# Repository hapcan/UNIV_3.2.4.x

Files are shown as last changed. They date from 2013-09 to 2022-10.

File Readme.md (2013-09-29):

UNIV 3.2.4.x
============

RELAY MODULE - 6 bistable 16A relays for DIN rail

Device webpage: http://hapcan.com/devices/universal/univ_3/univ_3-2-4-x/

Hardware created in Eagle PCB Software http://www.cadsoftusa.com/

Firmware created in Microchip MPLAB http://www.microchip.com/mplabide/ in assembly language

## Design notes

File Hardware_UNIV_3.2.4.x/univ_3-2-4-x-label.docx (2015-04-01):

K1 | K2 | K3 | K4 | K5 | K6

BISTABLE RELAY

6 CHANNEL

IN = 16A (IINRUSH = 30A)

UN = 250V AC
TYPE | UNIV 3.2.4.x
S/N | 00000569h
BUS BUS | | | hapcan.com

K1 | K2 | K3 | K4 | K5 | K6

PRZEKAŹNIK BISTABILNY

6 KANAŁOWY

IN = 16A (IROZRUCHOWY = 30A)

UN = 250V AC
TYP | UNIV 3.2.4.x
S/N | 00000569h
BUS BUS | | | hapcan.com

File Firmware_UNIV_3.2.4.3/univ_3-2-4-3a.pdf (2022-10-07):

## BISTABLE RELAY FIRMWARE

# UNIV 3.2.4.3

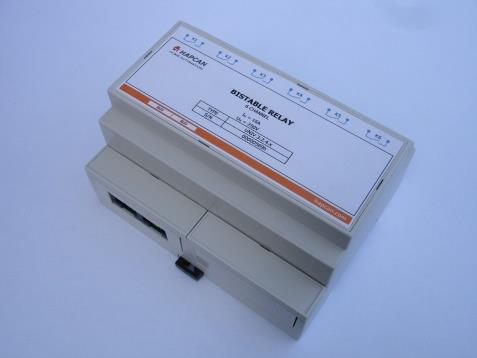
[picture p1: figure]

© 2022 hapcan.com | univ_3-2-4-3a.pdf - page 1 / 7

### 1. Features

- Firmware for 6 bistable relay module
- 3 control instructions (on, off, toggle)
- 3 blocking instructions
- 6 timers (1 for each relay) for instruction execution delay 1s-24h
- Allows defining up to 128 CAN messages which can indirectly control the module
- Settable relay power up state
- Settable relay coil polarity
- Uptime counter
- Health check monitor
- Transmit (42 messages) and receive (42 messages) FIFO buffers

### 2. Compatibility

- Firmware compatible with previous one UNIV 3.2.4.1
- Added CHANNEL NAME REQUEST frame (0x117).
- Firmware can be uploaded into processor with bootloader version 3.1 or compatible.

### 3. Firmware version

UNIV | 3 | . | 2 | . | 4 | . | 3
firmware version
application version (bistable relay 16A) application type (relay)
processor version
universal processor

### 4. Communication Frames (messages)

### 4.1. Relay message

The module sends message to the bus, when the status of relays changes.

Table 1. RELAY frame (0x302)
Frame type | Flags | Module | Group | D0 | D1 | D2 | D3 | D4 | D5 | D6 | D7
0x302 | 3 | 2 | 1 | 0 | Node Nr | Group Nr | 0xFF | 0xFF | CHANNEL | STATUS | 0xFF | INSTR1 | INSTR2 | TIMER
0x302 | – universal module frame, relay
3 | - | - not used flag, read as “0”
2 | - | - not used flag, read as “0”
1 | - | - not used flag, read as “0”
0 | RE | - response flag, flag is equal “1” if node was requested. If flag is equal „0” it means that status of output has just changed.
Node Nr | - message sender node number
Group Nr | - message sender group number
CHANNEL | - output channel
STATUS | - actual status of outputs 0x00 – relay off, 0xFF – relay on
INSTR1 | - instruction that is waiting for execution, or 0xFF if none instruction
INSTR2 | - second byte of instruction that is waiting for execution, or 0xFF
TIMER | - delay value of waiting instruction, or 0x00 if none waiting

### 4.2. Status request

Status of module can be checked by sending from computer STATUS REQUEST frame (0x109) (Table 2).

Table 2. STATUS REQUEST frame (0x109).
Frame type | Flags | Module | Group | D0 | D1 | D2 | D3 | D4 | D5 | D6 | D7
0x109 | 0x0 | COMP ID1 | COMP ID2 | 0xXX | 0xXX | Node Nr | Group Nr | 0xXX | 0xXX | 0xXX | 0xXX
0x1090 | – STATUS REQUEST frame
COMP ID1 | - computer identifier (must be unique on the network)
COMP ID2 | - computer identifier (must be unique on the network)
Node Nr | - node number of requested module
Group Nr | - group number of requested module
0xXX | - inessential data

As response the module will send RELAY frames. The meaning of bytes is the same as in Table 1.

Table 3. Response to STATUS REQUEST
Frame type | Flags | Module | Group | D0 | D1 | D2 | D3 | D4 | D5 | D6 | D7
0x302 | 0x1 | Node Nr | Group Nr | 0xFF | 0xFF | 0x01 | STATUS | 0xFF | INSTR1 | INSTR2 | TIMER1
Frame type | Flags | Module | Group | D0 | D1 | D2 | D3 | D4 | D5 | D6 | D7
0x302 | 0x1 | Node Nr | Group Nr | 0xFF | 0xFF | 0x02 | STATUS | 0xFF | INSTR1 | INSTR2 | TIMER2
Frame type | Flags | Module | Group | D0 | D1 | D2 | D3 | D4 | D5 | D6 | D7
0x302 | 0x1 | Node Nr | Group Nr | 0xFF | 0xFF | 0x03 | STATUS | 0xFF | INSTR1 | INSTR2 | TIMER3
Frame type | Flags | Module | Group | D0 | D1 | D2 | D3 | D4 | D5 | D6 | D7
0x302 | 0x1 | Node Nr | Group Nr | 0xFF | 0xFF | 0x04 | STATUS | 0xFF | INSTR1 | INSTR2 | TIMER4
Frame type | Flags | Module | Group | D0 | D1 | D2 | D3 | D4 | D5 | D6 | D7
0x302 | 0x1 | Node Nr | Group Nr | 0xFF | 0xFF | 0x05 | STATUS | 0xFF | INSTR1 | INSTR2 | TIMER5
Frame type | Flags | Module | Group | D0 | D1 | D2 | D3 | D4 | D5 | D6 | D7
0x302 | 0x1 | Node Nr | Group Nr | 0xFF | 0xFF | 0x06 | STATUS | 0xFF | INSTR1 | INSTR2 | TIMER6

### 4.3. Uptime request

Table 4. UPTIME REQUEST (0x113).
Frame type | Flags | Module | Group | D0 | D1 | D2 | D3 | D4 | D5 | D6 | D7
0x113 | 0x0 | COMP ID1 | COMP ID2 | 0xXX | 0xXX | Node Nr | Group Nr | 0xXX | 0xXX | 0xXX | 0xXX
0x1130 | – UPTIME REQUEST frame
COMP ID1 | - computer identifier (must be unique on the network)
COMP ID2 | - computer identifier (must be unique on the network)
Node Nr | - node number of requested module
Group Nr | - group number of requested module
0xXX | - inessential data

Table 5. Response to UPTIME REQUEST (0x113).
Frame type | Flags | Module | Group | D0 | D1 | D2 | D3 | D4 | D5 | D6 | D7
0x113 | 0x1 | Node Nr | Group Nr | 0xFF | 0xFF | 0xFF | 0xFF | UPTIME3 | UPTIME2 | UPTIME1 | UPTIME0
0x1131 | – Response to UPTIME REQUEST frame
Node Nr | - node number on the network
Group Nr | - group number of the node on the network
UPTIME | - (UPTIME3*256³+UPTIME2*256²+UPTIME1*256¹+UPTIME3*256⁰
) in seconds

### 4.4. Health check request

Table 6. HEALTH CHECK - STATUS REQUEST (0x115).
Frame type | Flags | Module | Group | D0 | D1 | D2 | D3 | D4 | D5 | D6 | D7
0x115 | 0x0 | COMP ID1 | COMP ID2 | 0x01 | 0xXX | Node Nr | Group Nr | 0xXX | 0xXX | 0xXX | 0xXX
0x1150 | – HEALTH CHECK REQUEST frame
COMP ID1 | - computer identifier (must be unique on the network)
COMP ID2 | - computer identifier (must be unique on the network)
0x01 | - status request
Node Nr | - node number of requested module
Group Nr | - group number of requested module
0xXX | - inessential data

As response the module will send two frames (Table 7).

Table 7. Response to HEALTH CHECK - STATUS REQUEST (0x115).
Frame type | Flags | Module | Group | D0 | D1 | D2 | D3 | D4 | D5 | D6 | D7
0x115 | 0x1 | Node Nr | Group Nr | 0x01 | RXCNT | TXCNT | RXCNTMX | TXCNTMX | CANINTCNT | RXERRCNT | TXERRCNT
0x1151 | – Response to HEALTH CHECK REQUEST frame
Node Nr | - node number on the network
Group Nr | - group number of the node on the network
0x01 | - frame 1 (current values)
RXCNT | - current level of receive FIFO buffer
TXCNT | - current level of transmit FIFO buffer
RXCNTMX | - maximum level of receive FIFO buffer since power up
TXCNTMX | - maximum level of transmit FIFO buffer since power up
CANINTCNT | - number of CAN interface restarts since power up
RXERRCNT | - current receive errors register
TXERRCNT | - current transmit errors register
Frame type | Flags | Module | Group | D0 | D1 | D2 | D3 | D4 | D5 | D6 | D7
0x115 | 0x1 | Node Nr | Group Nr | 0x02 | 0xFF | 0xFF | RXCNTMXE | TXCNTMXE | CANINTCNTE | RXERRCNTE | TXERRCNTE
0x1151 | – Response to HEALTH CHECK REQUEST frame
Node Nr | - node number on the network
Group Nr | - group number of the node on the network
0x02 | - frame 2 (maximum values saved in eeprom memory)
RXCNTMXE | - maximum ever level of receive FIFO buffer
TXCNTMXE | - maximum ever level of transmit FIFO buffer
CANINTCNTE | - maximum ever number of CAN interface restarts
RXERRCNTE | - maximum ever receive errors
TXERRCNTE | - maximum ever transmit errors

To clear maximum values saved in eeprom memory the frame shown in Table 8 must be sent. There is no response to this message.

Table 8. HEALTH CHECK - CLEAR REQUEST (0x115).
Frame type | Flags | Module | Group | D0 | D1 | D2 | D3 | D4 | D5 | D6 | D7
0x115 | 0x0 | COMP ID1 | COMP ID2 | 0x02 | 0xXX | Node Nr | Group Nr | 0xXX | 0xXX | 0xXX | 0xXX
0x1150 | – HEALTH CHECK REQUEST frame
COMP ID1 | - computer identifier (must be unique on the network)
COMP ID2 | - computer identifier (must be unique on the network)
0x02 | - clear request
Node Nr | - node number of requested module
Group Nr | - group number of requested module
0xXX | - inessential data

### 4.4. Channel name request

The module sends 5 frames for each channel containing name of channel (relay).

Table 1. CHANNEL NAME REQUEST (0x117).
Frame type | Flags | Module | Group | D0 | D1 | D2 | D3 | D4 | D5 | D6 | D7
0x117 | 0x0 | KOMP ID1 | KOMP ID2 | CHANNEL | 0xXX | Node Nr | Group Nr | 0xXX | 0xXX | 0xXX | 0xXX
0x1170 | – CHANNEL NAME REQUEST frame
COMP ID1 | - computer identifier (must be unique on the network)
COMP ID2 | - computer identifier (must be unique on the network)
CHANNEL | - requested channel number, 0x00-all channels
Node Nr | - node number of requested module
Group Nr | - group number of requested module
0xXX | - inessential data

Table 2. Response to CHANNEL NAME REQUEST (0x117).
Frame type | Flags | Module | Group | D0 | D1 | D2 | D3 | D4 | D5 | D6 | D7
0x117 | 0x1 | Node Nr | Group Nr | FRAMENR | Char1 | Char2 | Char3 | Char4 | Char5 | Char6 | Char7
0x117 | 0x1 | Node Nr | Group Nr | FRAMENR | Char8 | Char9 | Char10 | Char11 | Char12 | Char13 | Char14
0x117 | 0x1 | Node Nr | Group Nr | FRAMENR | Char15 | Char16 | Char17 | Char18 | Char19 | Char20 | Char21
0x117 | 0x1 | Node Nr | Group Nr | FRAMENR | Char22 | Char23 | Char24 | Char25 | Char26 | Char27 | Char28
0x117 | 0x1 | Node Nr | Group Nr | FRAMENR | Char29 | Char30 | Char31 | Char32 | 0x00 | 0x00 | 0x00
0x1171 | – Response to CHANNEL NAME REQUEST frame
Node Nr | - node number on the network
Group Nr | - group number of the node on the network
FRAMENR | - bits <7:3>-channel number, bits <2:1>-frame number (1-5)
| | | | CharX | - single char

### 5. Module control

The module can be controlled directly from PC, or indirectly by other modules. In both situation all instructions in the table below can be used. Blocking instructions can’t be used in direct control.

### 5.1. Control instruction

The Table 9 shows instructions, which can be executed by the module.

Table 9. Module control instructions

Instruction | Instruction Codding | Note | Control
INSTR1 | INSTR2 | INSTR3 | INSTR4 | INSTR5 | INSTR6 | INSTR7 | INSTR8
TURN OFF RELAY | 0x00 | CHANNEL | TIMER | 0xXX | 0xXX | 0xXX | 0xXX | 0xXX | It will turn off chosen relays, and the rest will stay unchanged. | √ | √
TURN ON RELAY | 0x01 | CHANNEL | TIMER | 0xXX | 0xXX | 0xXX | 0xXX | 0xXX | It will turn on chosen relays, and the rest will stay unchanged.
TOGGLE RELAY | 0x02 | CHANNEL | TIMER | 0xXX | 0xXX | 0xXX | 0xXX | 0xXX | It will toggle chosen relays, and the rest will stay unchanged.

Direct

Indirect

0xXX – inessential data

CHANNEL | Note
0x01 | - <00000001> - only relay K1
0x02 | - <00000010> - only relay K2
0x03 | - <00000011> - relay K1 & K2
0x04 | - <00000100> - only relay K3
…
0x3F | - <00111111> - relays K1,K2,K3,K4,K5,K6
bit <0> - relay K1, bit <1> - relay K2, bit <2> - relay K3
bit <3> - relay K4, bit <4> - relay K5, bit <5> - relay K6
TIMER | Note
0x00 | - instruction will be executed immediately
0x01 | - instruction will be executed with 1s delay
…
0xFF | - instruction will be executed with 24h delay

ENABLE BOX | 0xDD | BoxX | BoxY | 0xXX | 0xXX | 0xXX | 0xXX | 0xXX | It enables chosen boxes – these boxes will be compared with next received message from the bus. | √
DISABLE BOX | 0xDE | BoxX | BoxY | 0xXX | 0xXX | 0xXX | 0xXX | 0xXX | It disables chosen boxes – these boxes will be passed when next message arrives from the bus. | √
TOGGLE BOX | 0xDF | BoxX | BoxY | 0xXX | 0xXX | 0xXX | 0xXX | 0xXX | It toggles boxes – enables when they are disabled and vice versa | √

0xXX – inessential data

BoxX | Note
0x00 | - from Box 1
0x01 | - from Box 2
…
0x7F | - from Box 128
BoxY | Note
0x00 | + 0 -(and not anyone else)
0x01 | + 1 -( and 1 following)
…
0x7F | +127 -( and 127 following)

### 5.2. Timer

Each relay has its own timer which can delay execution of the instruction. Delay can be chosen between 1s-24h set in TIMER register. Drawing below shows delay dependence of TIMER register.

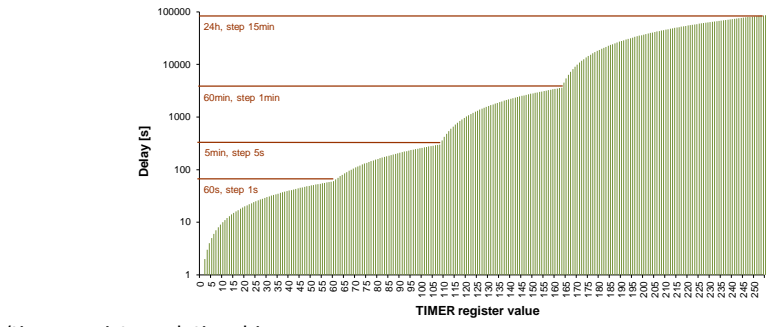
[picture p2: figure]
Delay [s]; TIMER register value; 60s, step 1s; 5min, step 5s; 60min, step 1min; 24h, step 15min

Figure 1. Delay/timer register relationship

### 5.3. Direct control

It is possible to control module by sending DIRECT CONTROL message. The message contains instruction, which will be executed by the module. The module can be also controlled from HAPCAN Programmer.

Table 10. DIRECT CONTROL frame (0x10A).
Frame type | Flags | Module | Group | D0 | D1 | D2 | D3 | D4 | D5 | D6 | D7
0x10A | 0x0 | COMP ID1 | COMP ID2 | INSTR1 | INSTR2 | Node Nr | Group Nr | INSTR3 | INSTR4 | INSTR5 | INSTR6
0x10A | – DIRECT CONTROL frame
COMP ID1 | - computer identifier (must be unique on the network)
COMP ID2 | - computer identifier (must be unique on the network)
Node Nr | - node number of requested module
Group Nr | - group number of requested module
INSTR1-6 | - instruction to be executed (byte1)

### 5.4. Indirect control

Indirect control means that module will react to messages sent by other modules on the network. It depends on configuration programmed into the module boxes (memory cells).
This firmware has feature to set simple conditions of executing instruction. To do so, you can use blocking instruction (0xDD – 0xDF) shown in Table 9.

### 6. Configuration

Below are parameters that can be configured with this firmware. Configuration process can be done using HAPCAN Programmer.

### 6.1. Module identifier

Every module on the network must have unique identifier. The identifier is made of two bytes, module number (1 byte) and group number (1 byte). Identifier of the Ethernet Interface can be changed in HAPCAN Programmer in software settings.

### 6.2. Module description

Every module can have 16 char description, which makes easier for user (programmer) to distinguish nodes.

### 6.3. Relay Names

Each relay can be named with 32 chars.

### 6.4. Power up values

It is possible to configure relay states at startup after power loss. At startup relays can be set to ON, OFF or to the last set value. The last set value must be unchanged for at least 6s before power failure.

### 6.5. Relay coil polarity

For each relay individually, you can determine the polarity of the coil: normal (if NO contact is closed when positive potential is connected to A1) or reversed (if NO contact is closed when positive potential is connected to A2).

6.6. Text notes.
Up to 1024 characters can be written into processor’s memory.

### 6.7. Linking devices

The indirect control is used to program the dependencies between modules. It is a controlling the module by messages sent from other modules. Each module when changing its status (eg when button is pressed or released in the button module) sends information that can be used to control the same module, as well as to control other modules located on the bus. For this purpose, the module has 128 boxes (memory cells) into which you can enter messages to which the module is to react when it receives them from the bus. Each box contains information about what message should initiate the action and what instruction should be made when this message is received.

In the figure on a side, the toggle instruction has been programmed, which changes the current state of the K2 relay at the moment of receiving a message from the module button o ID (4.1) - see the description of the BUTTON FRAME in the document "Firmware note" of the button module.

The message bytes are saved in hexadecimal format.

Operators at the front of bytes indicate that the module will react to a message received from the bus in which this byte:
x - can have any value
= - is identical to byte entered here
! - is different than byte entered here
< - is less or equal to byte entered here
> - is greater or equal to byte entered here

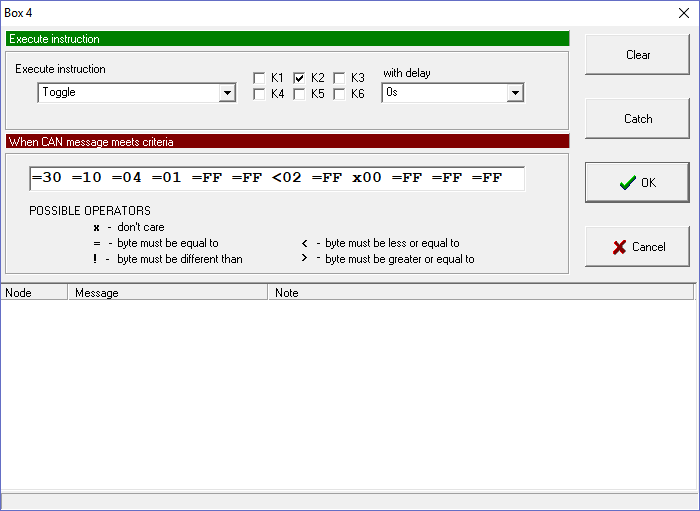
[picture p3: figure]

In this example:
=30 =10
=04 =01
=FF =FF
<02
=FF
x00

=FF =FF =FF

– button message
– module ID is (4,1)
– these bytes are not used and in button frame are always 0xFF
– button number is less or equal 2, means button number 1 or 2
– button is pressed
– it is a byte which gives LED status in the button module. Because we don’t want to make instruction execution to be depended on this byte, so this bute can have any value.
– these bytes are not used and in button frame are always 0xFF

As a result, the module will execute instructions when the module receives a message from the button with ID (4.1), when button number 1 or 2 has been pressed. Instruction is executed regardless of the LED status in the button module.

Each own and received from the bus message informing about the change of module status is checked with each active (enabled) box in the order from box no. 1 to 128. Therefore, you can set the reaction to the same message in two or more boxes. For example, in the first box instruction can be executed without delay, and in the next box another instruction can be executed after the defined time. It is important to keep the logical order of instruction executing to get the desired operation of the module. Calling an instruction that is to be executed without delay will cancel the previously set instruction with a delay.
Boxes can be dynamically activated (enabled) and deactivated (disabled). Blocking instructions are used for this (Table 9). In this way, you can control which boxes are to be checked after receiving the message.

### 7. License

MIT license

HAPCAN Home Automation Project firmware, Copyright © 2022 hapcan.com

Permission is hereby granted, free of charge, to any person obtaining a copy of this software and associated documentation files (the "Software"), to deal in the Software without restriction, including without limitation the rights to use, copy, modify, merge, publish, distribute, sublicense, and/or sell copies of the Software, and to permit persons to whom the Software is furnished to do so, subject to the following conditions:

The above copyright notice and this permission notice shall be included in all copies or substantial portions of the Software.

THE SOFTWARE IS PROVIDED "AS IS", WITHOUT WARRANTY OF ANY KIND, EXPRESS OR IMPLIED, INCLUDING BUT NOT LIMITED TO THE WARRANTIES OF MERCHANTABILITY, FITNESS FOR A PARTICULAR PURPOSE AND NONINFRINGEMENT. IN NO EVENT SHALL THE AUTHORS OR COPYRIGHT HOLDERS BE LIABLE FOR ANY CLAIM, DAMAGES OR OTHER LIABILITY, WHETHER IN AN ACTION OF CONTRACT, TORT OR OTHERWISE, ARISING FROM, OUT OF OR IN CONNECTION WITH THE SOFTWARE OR THE USE OR OTHER DEALINGS IN THE SOFTWARE.

### 8. Document version

File | Note | Date
univ_3-2-4-3a.pdf | Original version | October 2022

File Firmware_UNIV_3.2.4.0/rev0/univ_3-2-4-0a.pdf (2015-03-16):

# BISTABLE RELAY FIRMWARE

# UNIV 3.2.4.0

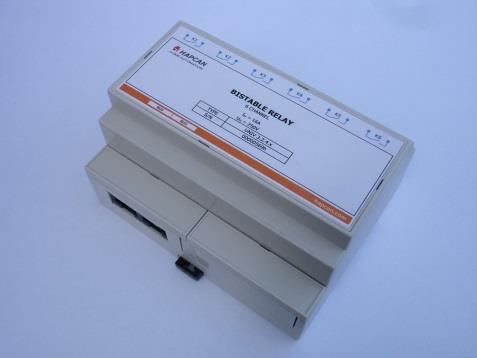
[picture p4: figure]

© 2013 hapcan.com | univ_3-2-4-0a.pdf - page 1 / 5

### 1. Features

- Firmware for 6 bistable relay module - 3 control instructions (on, off, toggle) - 3 blocking instructions - 6 timers (1 for each relay) for instruction execution delay 1s-24h - Allows defining up to 128 CAN messages which can indirectly control the module - Settable relay power up state - Uptime counter - Health check monitor - Transmit (42 messages) and receive (42 messages) FIFO buffers

### 2. Compatibility - Firmware for UNIV 3.2.4.x module - Firmware can be uploaded into processor with bootloader version 3.1 or

compatible.

### 3. Firmware version

UNIV | 3 | . | 2 | . | 4 | . | 0

### firmware version application version (bistable relay 16A) application type (relay) processor version universal processor

### 4. Communication Frames (messages)

### 4.1. Relay message

The module sends message to the bus, when the status of relays changes.

### Table 1. RELAY frame (0x302)

Frame type | Flags | Module | Group | D0 | D1 | D2 | D3 | D4 | D5 | D6 | D7
0x302 | 3 | 2 | 1 | 0 | Node Nr | Group Nr | 0xFF | 0xFF | CHANNEL | STATUS | 0xFF | INSTR1 | INSTR2 | TIMER
0x302 | – universal module frame, relay
3 | - | - not used flag, read as “0”
2 | - | - not used flag, read as “0”
1 | - | - not used flag, read as “0”
0 | RE | - response flag, flag is equal “1” if node was requested. If flag is equal „0” it means that status of output has just changed.
Node Nr | - message sender node number
Group Nr | - message sender group number
CHANNEL | - output channel
STATUS | - actual status of outputs 0x00 – relay off, 0xFF – relay on
INSTR1 | - instruction that is waiting for execution, or 0xFF if none instruction
INSTR2 | - second byte of instruction that is waiting for execution, or 0xFF
TIMER | - delay value of waiting instruction, or 0x00 if none waiting

## UNIV 3.2.4.0

### 4.2. Status request

Status of module can be checked by sending from computer STATUS REQUEST frame (0x109) (Table 2).

Table 2. STATUS REQUEST frame (0x109).
Frame type | Flags | Module | Group | D0 | D1 | D2 | D3 | D4 | D5 | D6 | D7
0x109 | 0x0 | COMP ID1 | COMP ID2 | 0xXX | 0xXX | Node Nr | Group Nr | 0xXX | 0xXX | 0xXX | 0xXX
0x1090 | – STATUS REQUEST frame
COMP ID1 | - computer identifier (must be unique on the network)
COMP ID2 | - computer identifier (must be unique on the network)
Node Nr | - node number of requested module
Group Nr | - group number of requested module
0xXX | - inessential data

As response the module will send RELAY frames. The meaning of bytes is the same as in Table1.

### Table 3. Response to STATUS REQUEST

Frame type | Flags | Module | Group | D0 | D1 | D2 | D3 | D4 | D5 | D6 | D7
0x302 | 0x1 | Node Nr | Group Nr | 0xFF | 0xFF | 0x01 | STATUS | 0xFF | INSTR1 | INSTR2 | TIMER
Frame type | Flags | Module | Group | D0 | D1 | D2 | D3 | D4 | D5 | D6 | D7
0x302 | 0x1 | Node Nr | Group Nr | 0xFF | 0xFF | 0x02 | STATUS | 0xFF | INSTR1 | INSTR2 | TIMER
Frame type | Flags | Module | Group | D0 | D1 | D2 | D3 | D4 | D5 | D6 | D7
0x302 | 0x1 | Node Nr | Group Nr | 0xFF | 0xFF | 0x03 | STATUS | 0xFF | INSTR1 | INSTR2 | TIMER
Frame type | Flags | Module | Group | D0 | D1 | D2 | D3 | D4 | D5 | D6 | D7
0x302 | 0x1 | Node Nr | Group Nr | 0xFF | 0xFF | 0x04 | STATUS | 0xFF | INSTR1 | INSTR2 | TIMER
Frame type | Flags | Module | Group | D0 | D1 | D2 | D3 | D4 | D5 | D6 | D7
0x302 | 0x1 | Node Nr | Group Nr | 0xFF | 0xFF | 0x05 | STATUS | 0xFF | INSTR1 | INSTR2 | TIMER
Frame type | Flags | Module | Group | D0 | D1 | D2 | D3 | D4 | D5 | D6 | D7
0x302 | 0x1 | Node Nr | Group Nr | 0xFF | 0xFF | 0x06 | STATUS | 0xFF | INSTR1 | INSTR2 | TIMER

### 4.3. Uptime request

Table 4. UPTIME REQUEST (0x113).
Frame type | Flags | Module | Group | D0 | D1 | D2 | D3 | D4 | D5 | D6 | D7
0x113 | 0x0 | COMP ID1 | COMP ID2 | 0xXX | 0xXX | Node Nr | Group Nr | 0xXX | 0xXX | 0xXX | 0xXX
0x1130 | – UPTIME REQUEST frame
COMP ID1 | - computer identifier (must be unique on the network)
COMP ID2 | - computer identifier (must be unique on the network)
Node Nr | - node number of requested module
Group Nr | - group number of requested module
0xXX | - inessential data

Table 5. Response to UPTIME REQUEST (0x113).
Frame type | Flags | Module | Group | D0 | D1 | D2 | D3 | D4 | D5 | D6 | D7
0x113 | 0x1 | Node Nr | Group Nr | 0xFF | 0xFF | 0xFF | 0xFF | UPTIME3 | UPTIME2 | UPTIME1 | UPTIME0
0x1131 | – Response to UPTIME REQUEST frame
Node Nr | - node number on the network
Group Nr | - group number of the node on the network
UPTIME | - (UPTIME3*256³+UPTIME2*256²+UPTIME1*256¹+UPTIME3*256⁰
) in seconds

### 4.4. Health check request

Table 6. HEALTH CHECK - STATUS REQUEST (0x115).
Frame type | Flags | Module | Group | D0 | D1 | D2 | D3 | D4 | D5 | D6 | D7
0x115 | 0x0 | COMP ID1 | COMP ID2 | 0x01 | 0xXX | Node Nr | Group Nr | 0xXX | 0xXX | 0xXX | 0xXX
0x1150 | – HEALTH CHECK REQUEST frame
COMP ID1 | - computer identifier (must be unique on the network)
COMP ID2 | - computer identifier (must be unique on the network)
0x01 | - status request
Node Nr | - node number of requested module
Group Nr | - group number of requested module
0xXX | - inessential data

As response the module will send two frames (Table 7).

Table 7. Response to HEALTH CHECK - STATUS REQUEST (0x115).
Frame type | Flags | Module | Group | D0 | D1 | D2 | D3 | D4 | D5 | D6 | D7
0x115 | 0x1 | Node Nr | Group Nr | 0x01 | RXCNT | TXCNT | RXCNTMX | TXCNTMX | CANINTCNT | RXERRCNT | TXERRCNT
0x1151 | – Response to HEALTH CHECK REQUEST frame
Node Nr | - node number on the network
Group Nr | - group number of the node on the network
0x01 | - frame 1 (current values)
RXCNT | - current level of receive FIFO buffer
TXCNT | - current level of transmit FIFO buffer
RXCNTMX | - maximum level of receive FIFO buffer since power up
TXCNTMX | - maximum level of transmit FIFO buffer since power up
CANINTCNT | - number of CAN interface restarts since power up
RXERRCNT | - current receive errors register
TXERRCNT | - current transmit errors register
Frame type | Flags | Module | Group | D0 | D1 | D2 | D3 | D4 | D5 | D6 | D7
0x115 | 0x1 | Node Nr | Group Nr | 0x02 | 0xFF | 0xFF | RXCNTMXE | TXCNTMXE | CANINTCNTE | RXERRCNTE | TXERRCNTE
0x1151 | – Response to HEALTH CHECK REQUEST frame
Node Nr | - node number on the network
Group Nr | - group number of the node on the network
0x02 | - frame 2 (maximum values saved in eeprom memory)
RXCNTMXE | - maximum ever level of receive FIFO buffer
TXCNTMXE | - maximum ever level of transmit FIFO buffer
CANINTCNTE | - maximum ever number of CAN interface restarts
RXERRCNTE | - maximum ever receive errors
TXERRCNTE | - maximum ever transmit errors

To clear maximum values saved in eeprom memory the frame shown in Table 8 must be sent. There is no response to this message.

Table 8. HEALTH CHECK - CLEAR REQUEST (0x115).
Frame type | Flags | Module | Group | D0 | D1 | D2 | D3 | D4 | D5 | D6 | D7
0x115 | 0x0 | COMP ID1 | COMP ID2 | 0x02 | 0xXX | Node Nr | Group Nr | 0xXX | 0xXX | 0xXX | 0xXX
0x1150 | – HEALTH CHECK REQUEST frame
COMP ID1 | - computer identifier (must be unique on the network)
COMP ID2 | - computer identifier (must be unique on the network)
0x02 | - clear request
Node Nr | - node number of requested module
Group Nr | - group number of requested module
0xXX | - inessential data

### 5. Module control

The module can be controlled directly from PC, or indirectly by other modules. In both situation all instructions in the table below can be used. Blocking instructions can’t be used in direct control.

### 5.1. Control instruction

The Table 9 shows instructions, which can be executed by the module.

### Table 9. Module control instructions

Instruction | Instruction code | Description INSTR1 | INSTR2 | INSTR3 | INSTR4 | INSTR5 | INSTR6 | INSTR7 | INSTR8
TURN OFF RELAY | 0x00 | CHANNEL | TIMER | 0xXX | 0xXX | 0xXX | 0xXX | 0xXX | It will turn off chosen relays, and the rest will stay unchanged.
TURN ON RELAY | 0x01 | CHANNEL | TIMER | 0xXX | 0xXX | 0xXX | 0xXX | 0xXX | It will turn on chosen relays, and the rest will stay unchanged.
TOGGLE RELAY | 0x02 | CHANNEL | TIMER | 0xXX | 0xXX | 0xXX | 0xXX | 0xXX | It will toggle chosen relays, and the rest will stay unchanged.

0xXX – inessential data
CHANNEL | Description
0x01 | - <00000001> - only relay K1
0x02 | - <00000010> - only relay K2
0x03 | - <00000011> - relay K1 & K2
0x04 | - <00000100> - only relay K3
…
0x3F | - <00111111> - relays K1,K2,K3,K4,K5,K6
bit <0> - relay K1
bit <1> - relay K2
bit <2> - relay K3
bit <3> - relay K4
bit <4> - relay K5
bit <5> - relay K6
TIMER | Description
0x00 | - instruction will be executed immediately
0x01 | - instruction will be executed with 1s delay
…
0xFF | - instruction will be executed with 24h delay

### 5.2. Timer

Each relay has its own timer which can delay execution of the instruction. Delay can be chosen between 1s-24h set in TIMER register. Drawing below shows delay dependence of TIMER register.

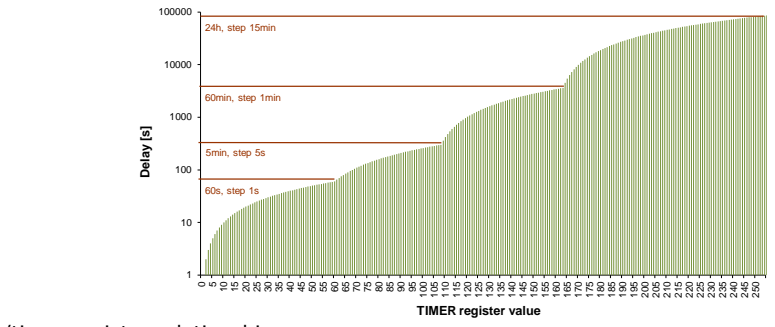
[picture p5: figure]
Delay [s]; TIMER register value; 60s, step 1s; 5min, step 5s; 60min, step 1min; 24h, step 15min

### Figure 1. Delay/timer register relationship

### 5.3. Direct control

It is possible to control module by sending DIRECT CONTROL message. The message contains instruction, which will be executed by the module. The module can be also controlled from HAPCAN Programmer.

Table 10. DIRECT CONTROL frame (0x10A).
Frame type | Flags | Module | Group | D0 | D1 | D2 | D3 | D4 | D5 | D6 | D7
0x10A | 0x0 | COMP ID1 | COMP ID2 | INSTR1 | INSTR2 | Node Nr | Group Nr | INSTR3 | INSTR4 | INSTR5 | INSTR6
0x10A | – DIRECT CONTROL frame
COMP ID1 | - computer identifier (must be unique on the network)
COMP ID2 | - computer identifier (must be unique on the network)
Node Nr | - node number of requested module
Group Nr | - group number of requested module
INSTR1-6 | - instruction to be executed (byte1)

### 5.4. Indirect control

Indirect control means that module will react to messages sent by other modules on the network. It depends on configuration programmed into the module boxes (memory cells).
This firmware has feature to set simple conditions of executing instruction. To do so, you can use blocking instruction shown in the table below. As an example of simple condition can be situation when light has to be turned on by PIR when someone enters room, but should not be during a day. The HAPCAN Programmer simplifies configuration process.

### Table 11. Coding of blocking instructions

Instruction | Instruction code | Description INSTR1 | INSTR2 | INSTR3 | INSTR4 | INSTR5 | INSTR6 | INSTR7 | INSTR8
ENABLE BOX | 0xDD | BoxX | BoxY | 0xXX | 0xXX | 0xXX | 0xXX | 0xXX | It enables chosen boxes – these boxes will be compared with next received message from the bus.
DISABLE BOX | 0xDE | BoxX | BoxY | 0xXX | 0xXX | 0xXX | 0xXX | 0xXX | It disables chosen boxes – these boxes will be passed when next message arrives from the bus.
TOGGLE BOX | 0xDF | BoxX | BoxY | 0xXX | 0xXX | 0xXX | 0xXX | 0xXX | It toggles boxes – enables when they are disabled and vice versa

0xXX – inessential data
BoxX | Description
0x00 | - from Box 1
0x01 | - from Box 2
…
0x7F | - from Box 128
BoxY | Opis
0x00 | + 0 -(and not anyone else)
0x01 | + 1 -( and 1 following)
…
0x7F | +128 -( and 128 following)

### 6. Configuration Parameters that can be configured with this firmware:

- Module identifier (module number and group number);
- Module description (16 chars);
- Power up values;
- Text notes;
- Linking device with other modules (indirect control of module). Configuration process can be done using HAPCAN Programmer.

### 6.1. Module identifier

Every module on the network must have unique identifier. The identifier is made of two bytes, module number (1 byte) and group number (1 byte). Identifier of the Ethernet Interface can be changed in HAPCAN Programmer in software settings.

### 6.2. Module description

Every module can have 16 char description, which makes easier for user (programmer) to distinguish nodes.

### 6.3. Power up values

It is possible to configure relay states at startup after power loss. At startup relays can be set to ON, OFF or to the last set value. The last set value must be unchanged for at least 6s before power failure.

6.4. Text notes.
Up to 1024 characters can be written into processor’s memory.

### 6.5. Linking devices

The module has 128 memory cells (boxes). Each box can contain information about message sent by other node, and instruction which will be executed when that message is received.

### 7. License

HAPCAN Home Automation Project firmware, Copyright (C) 2013 hapcan.com

This program is free firmware: you can redistribute it and/or modify it under the terms of the GNU General Public License as published by the Free Software Foundation, either version 3 of the License, or (at your option) any later version.

This firmware is distributed in the hope that it will be useful, but WITHOUT ANY WARRANTY; without even the implied warranty of MERCHANTABILITY or FITNESS FOR A PARTICULAR PURPOSE. See the GNU General Public License for more details.

You should have received a copy of the GNU General Public License along with this firmware. If not, see http://www.gnu.org/licenses/gpl-3.0.html.

### 8. Document version

File | Note | Date
univ_3-2-4-0a.pdf | Original version | July 2013

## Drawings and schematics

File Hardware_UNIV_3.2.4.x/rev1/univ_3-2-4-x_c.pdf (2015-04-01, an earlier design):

## BISTABLE RELAY 16A

# UNIV 3.2.4.x

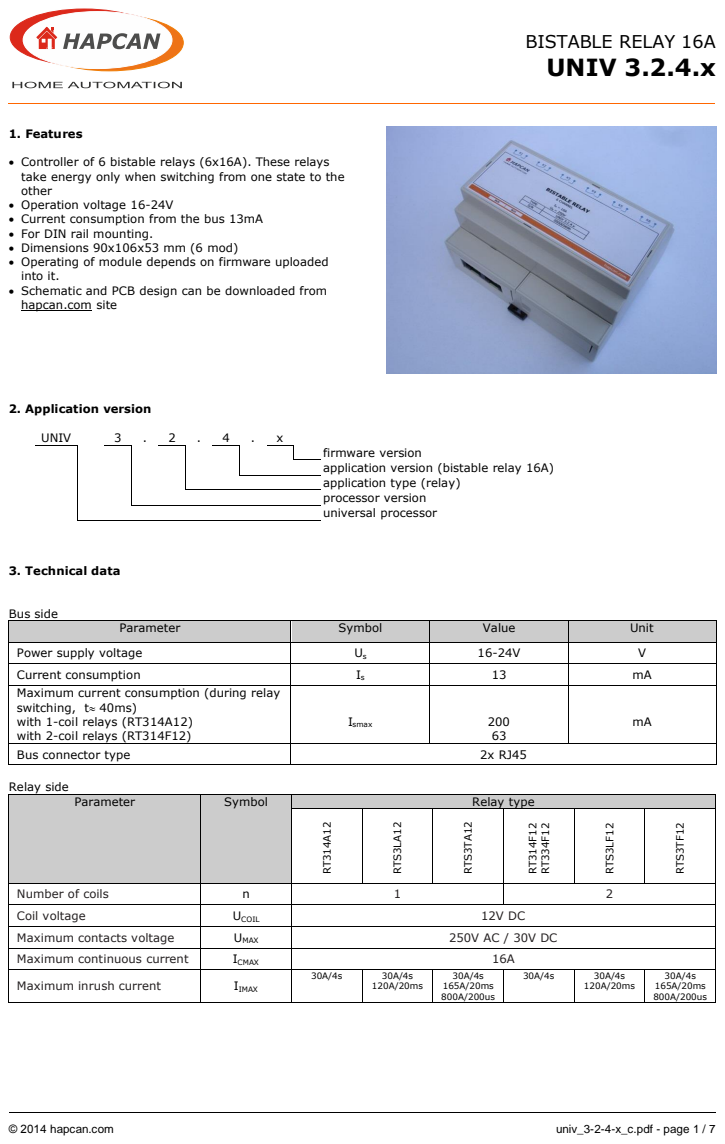
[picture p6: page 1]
© 2014 hapcan.com; univ_3-2-4-x_c.pdf - page 1 / 7; 1. Features; 2. Application version; UNIV; 3. Technical data; Bus side; Relay side; RTS3LF12; RTS3TF12

• Controller of 6 bistable relays (6x16A). These relays
take energy only when switching from one state to the
other
• Operation voltage 16-24V
• Current consumption from the bus 13mA
• For DIN rail mounting.
• Dimensions 90x106x53 mm (6 mod)
• Operating of module depends on firmware uploaded
into it.
• Schematic and PCB design can be downloaded from
hapcan.com site

firmware version
application version (bistable relay 16A)
application type (relay)
processor version
universal processor

Parameter | Symbol | Value | Unit

Power supply voltage | Us | 16-24V | V

Current consumption | Is | 13 | mA
Maximum current consumption (during relay switching, t≈ 40ms) with 1-coil relays (RT314A12) with 2-coil relays (RT314F12) | Ismax | 200 63 | mA

Bus connector type | 2x RJ45

Parameter | Symbol

RTS3LA12 | RTS3TA12 Relay type RT314A12 | RT314F12

Number of coils | n | 1 | | | 2

Coil voltage | UCOIL | 12V DC

Maximum contacts voltage | UMAX | 250V AC / 30V DC

Maximum continuous current | ICMAX | 16A
Maximum inrush current | IIMAX | 30A/4s | 30A/4s 120A/20ms | 30A/4s 165A/20ms 800A/200us | 30A/4s | 30A/4s 120A/20ms | 30A/4s 165A/20ms 800A/200us

## UNIV 3.2.4.x

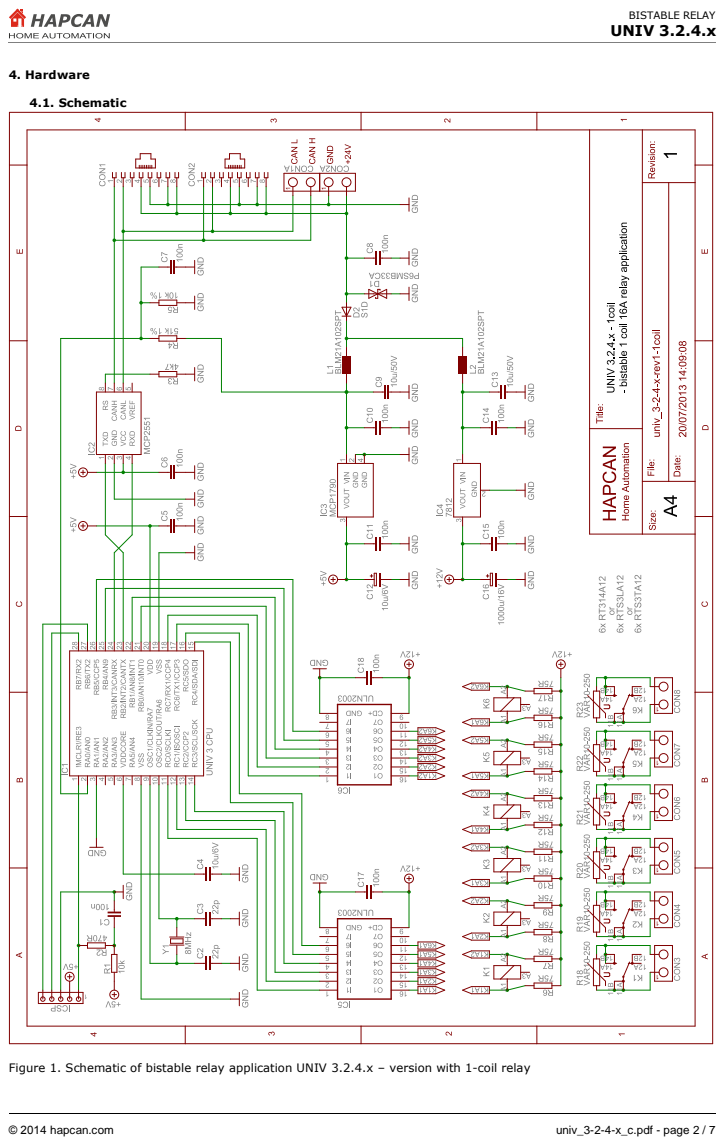
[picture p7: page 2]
BISTABLE RELAY; 4. Hardware; 4.1. Schematic

Figure 1. Schematic of bistable relay application UNIV 3.2.4.x – version with 1-coil relay

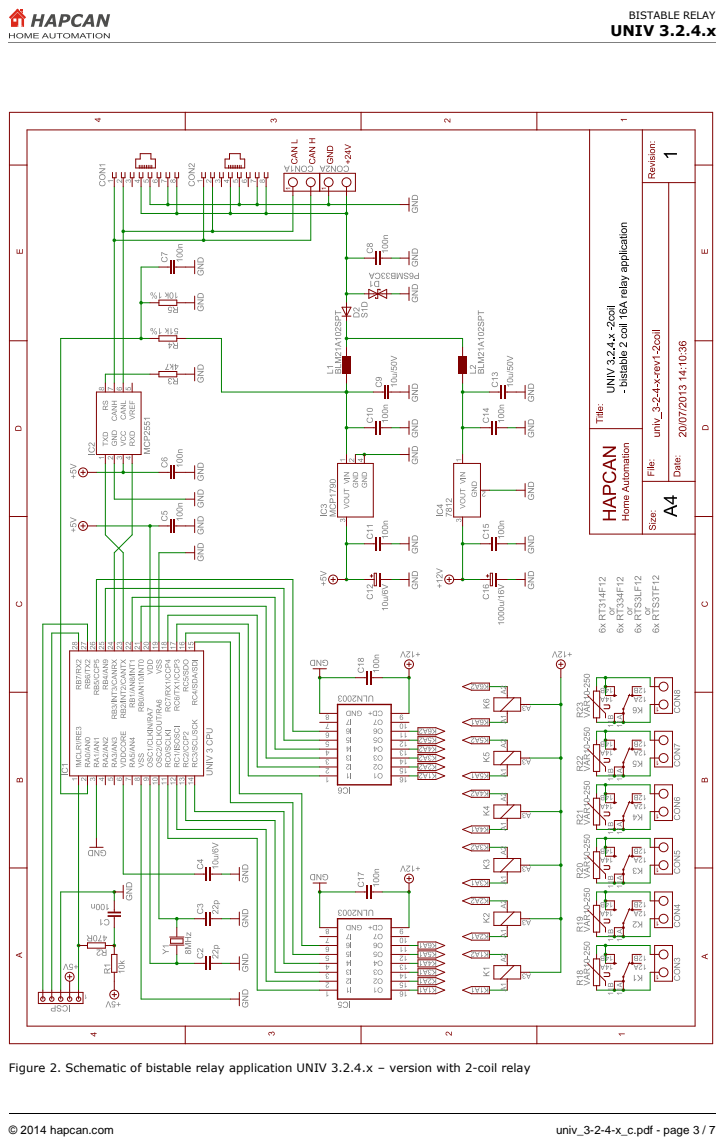
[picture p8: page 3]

Figure 2. Schematic of bistable relay application UNIV 3.2.4.x – version with 2-coil relay

M

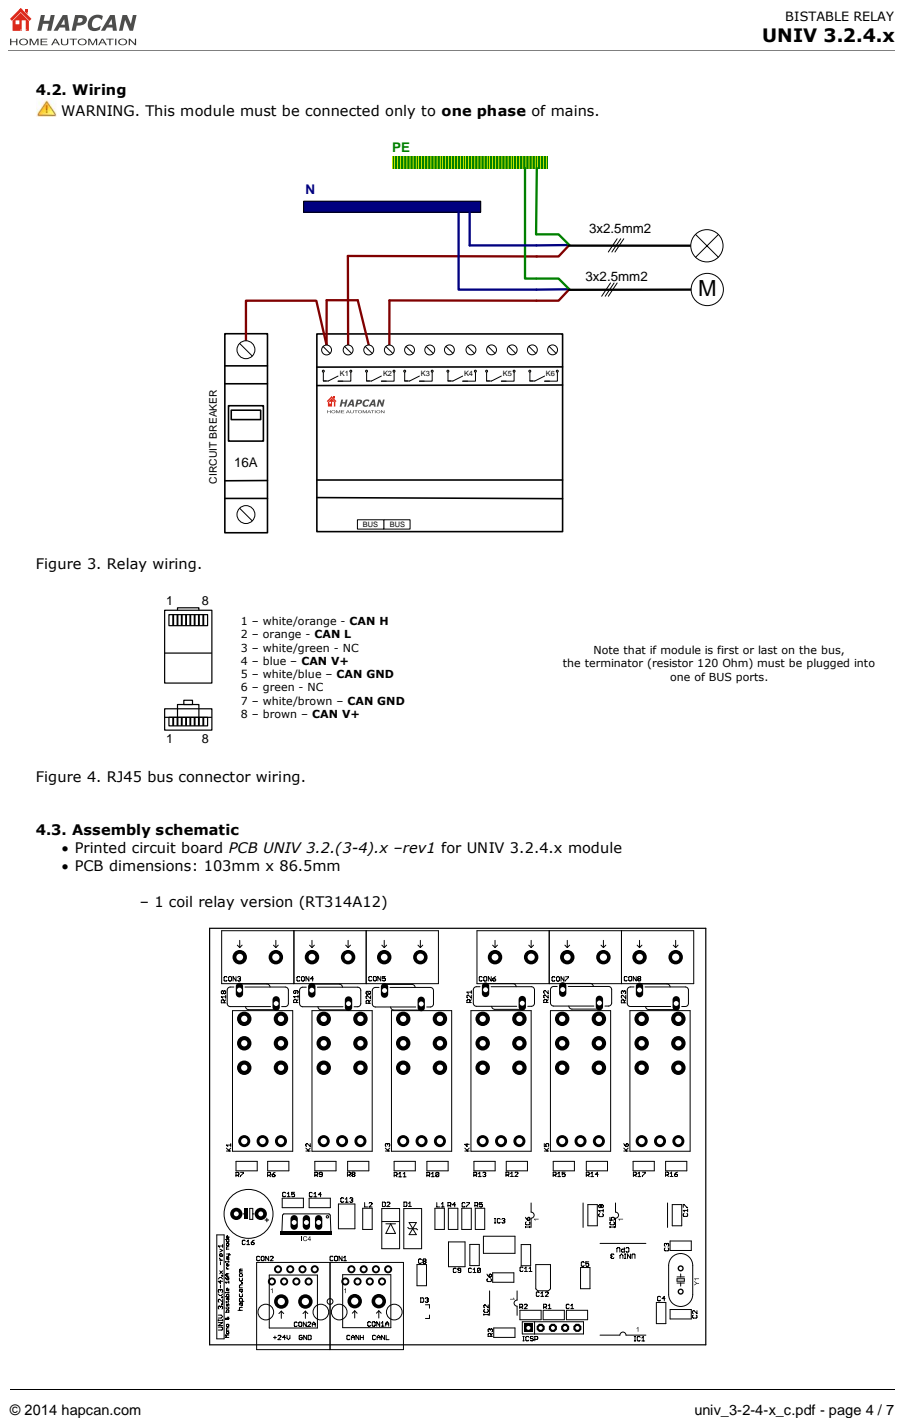
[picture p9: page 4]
CIRCUIT BREAKER 16A; BUS

4.2. Wiring
WARNING. This module must be connected only to one phase of mains.

Figure 3. Relay wiring.

1 – white/orange - CAN H
2 – orange - CAN L
3 – white/green - NC
4 – blue – CAN V+
5 – white/blue – CAN GND
6 – green - NC
7 – white/brown – CAN GND
8 – brown – CAN V+

Note that if module is first or last on the bus,
the terminator (resistor 120 Ohm) must be plugged into

one of BUS ports.

Figure 4. RJ45 bus connector wiring.

4.3. Assembly schematic
• Printed circuit board PCB UNIV 3.2.(3-4).x –rev1 for UNIV 3.2.4.x module
• PCB dimensions: 103mm x 86.5mm

– 1 coil relay version (RT314A12)

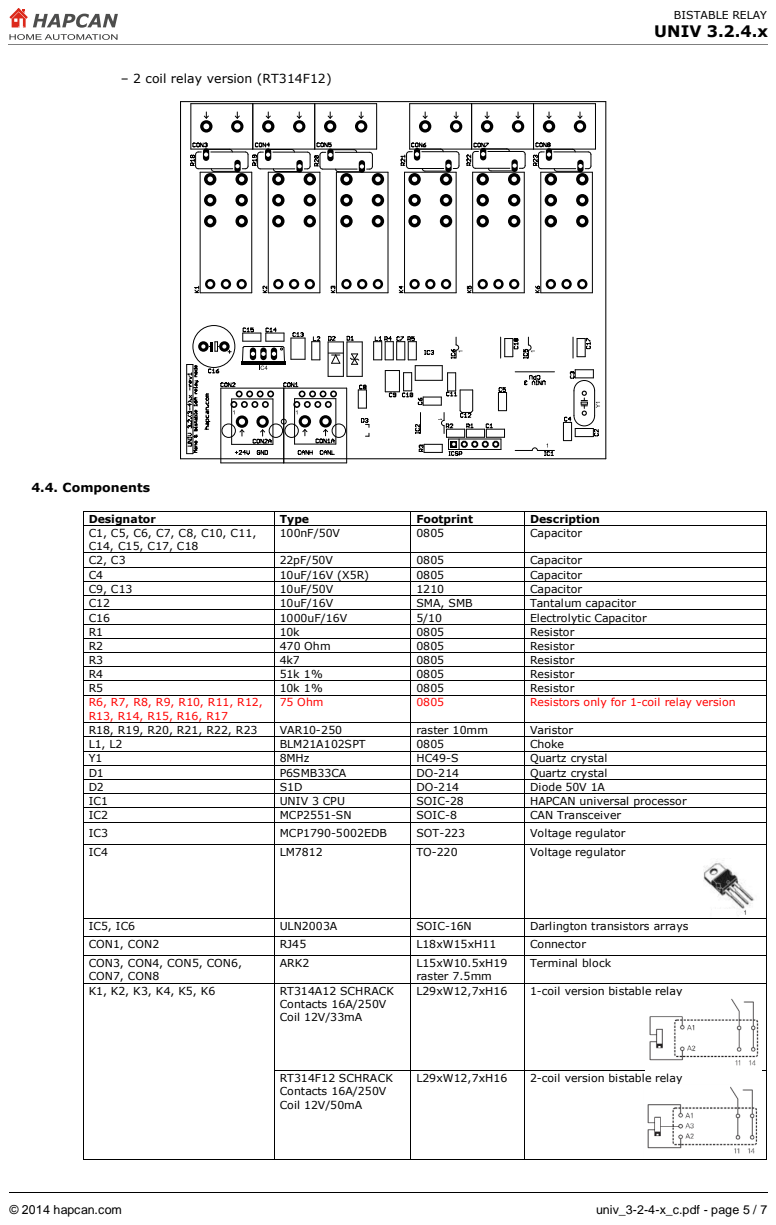
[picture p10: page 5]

Designator | Type | Footprint | Description
C1, C5, C6, C7, C8, C10, C11, C14, C15, C17, C18 | 100nF/50V | 0805 | Capacitor

C2, C3 | 22pF/50V | 0805 | Capacitor
C4 | 10uF/16V (X5R) | 0805 | Capacitor
C9, C13 | 10uF/50V | 1210 | Capacitor
C12 | 10uF/16V | SMA, SMB | Tantalum capacitor
C16 | 1000uF/16V | 5/10 | Electrolytic Capacitor
R1 | 10k | 0805 | Resistor
R2 | 470 Ohm | 0805 | Resistor
R3 | 4k7 | 0805 | Resistor
R4 | 51k 1% | 0805 | Resistor
R5 | 10k 1% | 0805 | Resistor
R6, R7, R8, R9, R10, R11, R12, R13, R14, R15, R16, R17 | 75 Ohm | 0805 | Resistors only for 1-coil relay version

R18, R19, R20, R21, R22, R23 | VAR10-250 | raster 10mm | Varistor
L1, L2 | BLM21A102SPT | 0805 | Choke
Y1 | 8MHz | HC49-S | Quartz crystal
D1 | P6SMB33CA | DO-214 | Quartz crystal
D2 | S1D | DO-214 | Diode 50V 1A
IC1 | UNIV 3 CPU | SOIC-28 | HAPCAN universal processor
IC2 | MCP2551-SN | SOIC-8 | CAN Transceiver
IC3 | MCP1790-5002EDB | SOT-223 | Voltage regulator
IC4 | LM7812 | TO-220 | Voltage regulator

IC5, IC6 | ULN2003A | SOIC-16N | Darlington transistors arrays
CON1, CON2 | RJ45 | L18xW15xH11 | Connector
CON3, CON4, CON5, CON6, CON7, CON8 | ARK2 | L15xW10.5xH19 raster 7.5mm | Terminal block

K1, K2, K3, K4, K5, K6 | RT314A12 SCHRACK Contacts 16A/250V Coil 12V/33mA | L29xW12,7xH16 | 1-coil version bistable relay

RT314F12 SCHRACK Contacts 16A/250V Coil 12V/50mA | L29xW12,7xH16 | 2-coil version bistable relay

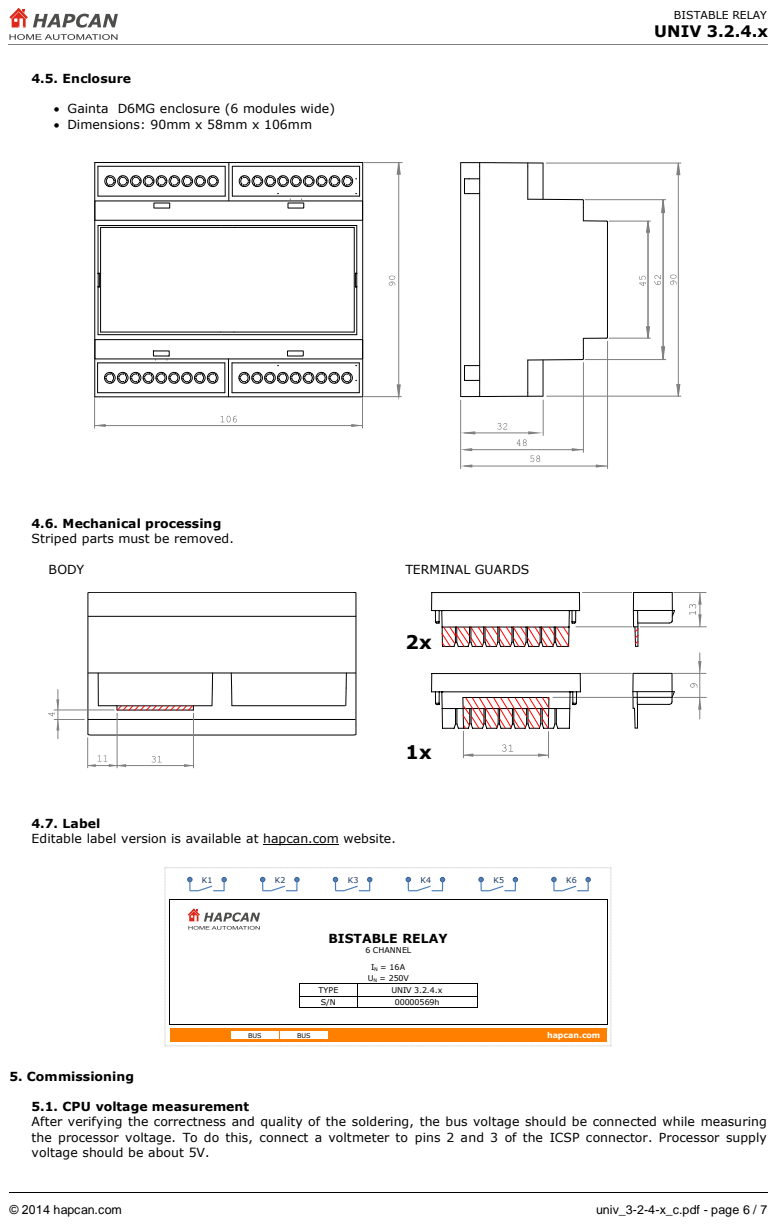
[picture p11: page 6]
4.5. Enclosure; BODY; TERMINAL GUARDS; BISTABLE RELAY; 6 CHANNEL; BUS; hapcan.com; 5. Commissioning

• Gainta D6MG enclosure (6 modules wide)
• Dimensions: 90mm x 58mm x 106mm

4.6. Mechanical processing
Striped parts must be removed.

4.7. Label
Editable label version is available at hapcan.com website.

TYPE | UNIV 3.2.4.x
S/N | 00000569h

5.1. CPU voltage measurement
After verifying the correctness and quality of the soldering, the bus voltage should be connected while measuring
the processor voltage. To do this, connect a voltmeter to pins 2 and 3 of the ICSP connector. Processor supply
voltage should be about 5V.

Figure 3. CPU voltage measurement
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

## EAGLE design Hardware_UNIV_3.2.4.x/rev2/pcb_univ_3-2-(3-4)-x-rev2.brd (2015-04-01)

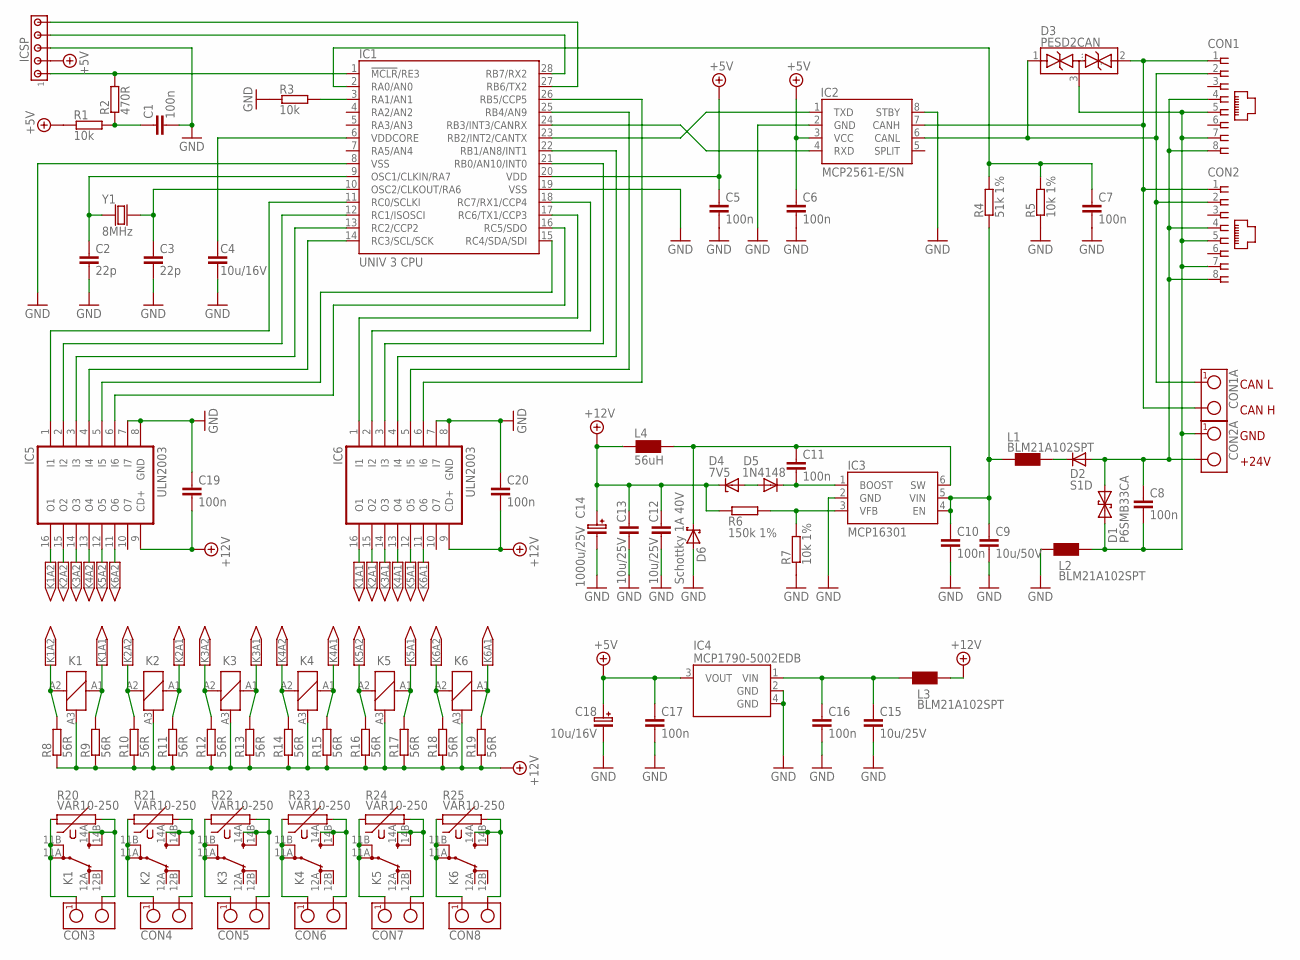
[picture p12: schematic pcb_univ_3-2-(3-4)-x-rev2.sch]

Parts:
C1, C5, C6, C7, C8, C10, C11, C16, C17, C19, C20: 100n; 0805
C2, C3: 22p; 0805
C4: 10u/16V; 0805
C9: 10u/50V; 1210
C12, C13, C15: 10u/25V; 1206
C14: 1000u/25V; CAP-5X10.5
C18: 10u/16V; SMC_B
CON1, CON2: RJ45-SOCKET; RJ45-PCB-SOCKET
CON1A, CON2A: TERMINAL-2; ARK2-5X10,5MM
CON3, CON4, CON5, CON6, CON7, CON8: TERMINAL-2; ARK2-7.5X10.5MM
D1: P6SMB33CA; DO-214_TRANSIL2
D2: S1D; DO-214
D3: PESD2CAN; SOT-23
D4: 7V5; SOD-80
D5: 1N4148; 0805
D6: Schottky 1A 40V; DO-214
IC1: UNIV 3 CPU; UNIV3CPU
IC2: MCP2561-E/SN; SO-08
IC3: MCP16301; SOT-23-6
IC4: MCP1790-5002EDB; SOT-223
IC5, IC6: ULN2003; SO-16
ICSP: HEADER5; SIP-5
K1, K2, K3, K4, K5, K6: RELAY_RT
L1, L2, L3: BLM21A102SPT; 0805
L4: 56uH; CHOKE-DER0705
R1, R3: 10k; 0805
R2: 470R; 0805
R4: 51k 1%; 0805
R5, R7: 10k 1%; 0805
R6: 150k 1%; 0805
R8, R9, R10, R11, R12, R13, R14, R15, R16, R17, R18, R19: 56R; 1206
R20, R21, R22, R23, R24, R25: VAR10-250; VARISTOR1
Y1: 8MHz; CRYSTAL-HC49V

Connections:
+5V: C5.1, C6.1, C17.1, C18.+ (1), IC1.20 (VDD), IC2.3 (VCC), IC4.3 (VOUT), ICSP.2, R1.1
+12V: C12.1, C13.1, C14.+ (1), C19.2, C20.2, D4.C, IC5.9 (CD+), IC6.9 (CD+), K1.A3 (-), K2.A3 (-), K3.A3 (-), K4.A3 (-), K5.A3 (-), K6.A3 (-), L3.2, L4.1, R6.1, R8.1, R9.1, R10.1, R11.1, R12.1, R13.1, R14.1, R15.1, R16.1, R17.1, R18.1, R19.1
GND: C1.2, C2.2, C3.2, C4.2, C5.2, C6.2, C7.2, C9.2, C10.2, C12.2, C13.2, C14.- (2), C15.2, C16.2, C17.2, C18.- (2), C19.1, C20.1, D6.A, IC1.8 (VSS), IC1.19 (VSS), IC2.2 (GND), IC2.8 (STBY), IC3.2 (GND), IC4.2 (GND), IC4.4 (GND), IC5.7 (I7), IC5.8 (GND), IC6.7 (I7), IC6.8 (GND), ICSP.3, L2.1, R3.1, R5.1, R7.1
K1A1: IC6.16 (O1), K1.A1 (S+), R9.2
K1A2: IC5.16 (O1), K1.A2 (R+), R8.2
K2A1: IC6.15 (O2), K2.A1 (S+), R11.2
K2A2: IC5.15 (O2), K2.A2 (R+), R10.2
K3A1: IC6.14 (O3), K3.A1 (S+), R13.2
K3A2: IC5.14 (O3), K3.A2 (R+), R12.2
K4A1: IC6.13 (O4), K4.A1 (S+), R15.2
K4A2: IC5.13 (O4), K4.A2 (R+), R14.2
K5A1: IC6.12 (O5), K5.A1 (S+), R17.2
K5A2: IC5.12 (O5), K5.A2 (R+), R16.2
K6A1: IC6.11 (O6), K6.A1 (S+), R19.2
K6A2: IC5.11 (O6), K6.A2 (R+), R18.2
unnamed: D2.C, L1.2
unnamed: IC1.24 (RB3/INT3/CANRX), IC2.4 (RXD)
unnamed: IC1.23 (RB2/INT2/CANTX), IC2.1 (TXD)
unnamed: CON1.1, CON1A.2, CON2.1, D3.2 (..), IC2.7 (CANH)
unnamed: C9.1, C10.1, IC3.4 (EN), IC3.5 (VIN), L1.1, R4.1
unnamed: C15.1, C16.1, IC4.1 (VIN), L3.1
unnamed: C1.1, R1.2, R2.1
unnamed: IC1.1 (!MCLR!/RE3), ICSP.1, R2.2
unnamed: C8.1, CON1.4, CON1.8, CON2.4, CON2.8, CON2A.2, D1.C (2), D2.A
unnamed: IC1.28 (RB7/RX2), ICSP.4
unnamed: IC1.12 (RC1/ISOSCI), IC5.2 (I2)
unnamed: IC1.3 (RA1/AN1), R3.2
unnamed: C8.2, CON1.5, CON1.7, CON2.5, CON2.7, CON2A.1, D1.A (1), D3.3 (...), L2.2
unnamed: IC1.27 (RB6/TX2), ICSP.5
unnamed: C3.1, IC1.10 (OSC2/CLKOUT/RA6), Y1.2
unnamed: C7.1, IC1.2 (RA0/AN0), R4.2, R5.2
unnamed: C11.1, D6.C, IC3.6 (SW), L4.2
unnamed: IC1.11 (RC0/SCLKI), IC5.1 (I1)
unnamed: IC1.13 (RC2/CCP2), IC5.3 (I3)
unnamed: IC3.3 (VFB), R6.2, R7.2
unnamed: IC1.14 (RC3/SCL/SCK), IC5.4 (I4)
unnamed: D4.A, D5.2 (A)
unnamed: IC1.15 (RC4/SDA/SDI), IC5.5 (I5)
unnamed: CON1.2, CON1A.1, CON2.2, D3.1 (.), IC2.6 (CANL)
unnamed: CON3.1, K1.11A (PA), K1.11B (PB), R20.1
unnamed: CON3.2, K1.14A (SA), K1.14B (SB), R20.2
unnamed: C11.2, D5.1 (C), IC3.1 (BOOST)
unnamed: C2.1, IC1.9 (OSC1/CLKIN/RA7), Y1.1
unnamed: IC1.16 (RC5/SDO), IC5.6 (I6)
unnamed: IC1.17 (RC6/TX1/CCP3), IC6.1 (I1)
unnamed: IC1.18 (RC7/RX1/CCP4), IC6.2 (I2)
unnamed: CON4.2, K2.14A (SA), K2.14B (SB), R21.2
unnamed: CON5.2, K3.14A (SA), K3.14B (SB), R22.2
unnamed: CON6.2, K4.14A (SA), K4.14B (SB), R23.2
unnamed: CON7.2, K5.14A (SA), K5.14B (SB), R24.2
unnamed: CON8.2, K6.14A (SA), K6.14B (SB), R25.2
unnamed: C4.1, IC1.6 (VDDCORE)
unnamed: CON4.1, K2.11A (PA), K2.11B (PB), R21.1
unnamed: CON5.1, K3.11A (PA), K3.11B (PB), R22.1
unnamed: CON6.1, K4.11A (PA), K4.11B (PB), R23.1
unnamed: CON7.1, K5.11A (PA), K5.11B (PB), R24.1
unnamed: CON8.1, K6.11A (PA), K6.11B (PB), R25.1
unnamed: IC1.21 (RB0/AN10/INT0), IC6.3 (I3)
unnamed: IC1.22 (RB1/AN8/INT1), IC6.4 (I4)
unnamed: IC1.25 (RB4/AN9), IC6.5 (I5)
unnamed: IC1.26 (RB5/CCP5), IC6.6 (I6)

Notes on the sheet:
CAN L
CAN H
GND
+24V

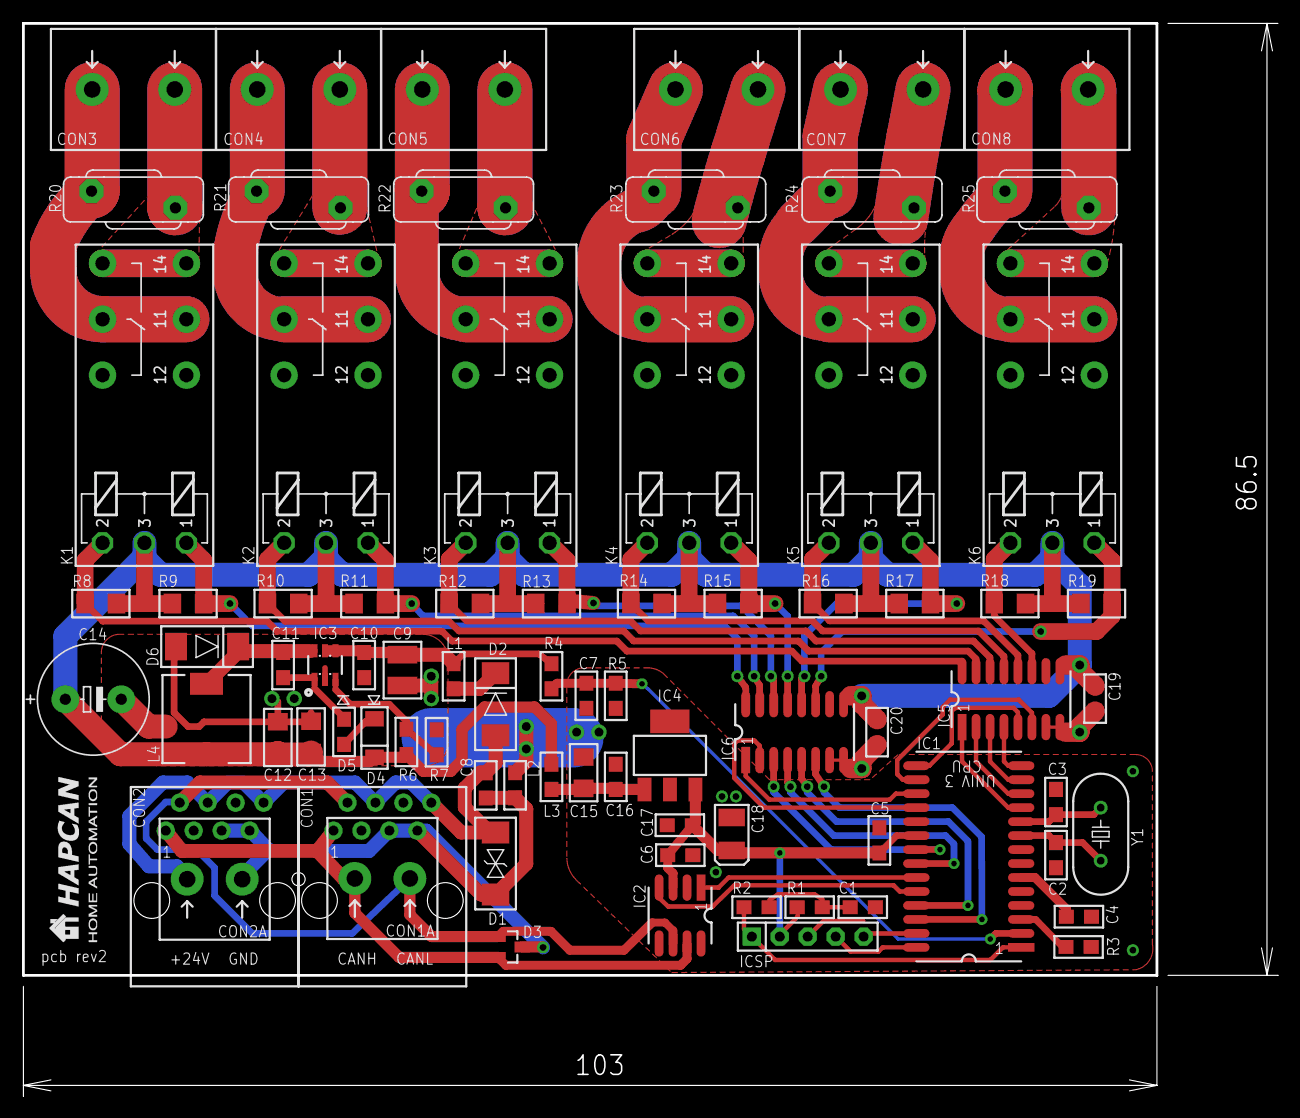
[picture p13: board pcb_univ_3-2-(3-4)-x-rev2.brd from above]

Board: 2 copper layers, 103.0 x 86.5 mm, 79 parts (0 on the bottom side), 61 nets.

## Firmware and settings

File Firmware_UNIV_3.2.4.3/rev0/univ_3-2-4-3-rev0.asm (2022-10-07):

;==============================================================================
;   MIT License
;
;   Copyright (c) 2022 HAPCAN Home Automation Project (http://hapcan.com)
;
;   Permission is hereby granted, free of charge, to any person obtaining a copy
;   of this software and associated documentation files (the "Software"), to deal
;   in the Software without restriction, including without limitation the rights
;   to use, copy, modify, merge, publish, distribute, sublicense, and/or sell
;   copies of the Software, and to permit persons to whom the Software is
;   furnished to do so, subject to the following conditions:
;
;   The above copyright notice and this permission notice shall be included in all
;   copies or substantial portions of the Software.
;
;   THE SOFTWARE IS PROVIDED "AS IS", WITHOUT WARRANTY OF ANY KIND, EXPRESS OR
;   IMPLIED, INCLUDING BUT NOT LIMITED TO THE WARRANTIES OF MERCHANTABILITY,
;   FITNESS FOR A PARTICULAR PURPOSE AND NONINFRINGEMENT. IN NO EVENT SHALL THE
;   AUTHORS OR COPYRIGHT HOLDERS BE LIABLE FOR ANY CLAIM, DAMAGES OR OTHER
;   LIABILITY, WHETHER IN AN ACTION OF CONTRACT, TORT OR OTHERWISE, ARISING FROM,
;   OUT OF OR IN CONNECTION WITH THE SOFTWARE OR THE USE OR OTHER DEALINGS IN THE
;   SOFTWARE.
;==============================================================================
;   Filename:              univ_3-2-4-3.asm
;   Associated diagram:    univ_3-2-4-x.sch
;   Author:                Jacek Siwilo                          
;   Note:                  Bistable Relay
;==============================================================================
;   Revision History
;   Rev:  Date:     Details:
;   0     10.2022   Original version
;==============================================================================
;===  FIRMWARE DEFINITIONS  =================================================== 
;==============================================================================
    #define    ATYPE    .2                            ;application type [0-255]
    #define    AVERS    .4                         ;application version [0-255]
    #define    FVERS    .3                            ;firmware version [0-255]

    #define    FREV     .0                         ;firmware revision [0-65536]
;==============================================================================
;===  NEEDED FILES  ===========================================================
;==============================================================================
    LIST P=18F26K80                              ;directive to define processor
    #include <P18F26K80.INC>           ;processor specific variable definitions
    #include <univ_3-2-4-3-rev0.inc>                         ;project variables
INCLUDEDFILES   code
    #include <univ3-routines-rev9.inc>                     ;UNIV 3 CPU routines
;==============================================================================
;===  FIRMWARE CHECKSUM  ======================================================
;==============================================================================
FIRMCHKSM   code    0x001000
    DB      0x65, 0x73, 0x0B
;==============================================================================
;===  FIRMWARE ID  ============================================================
;==============================================================================
FIRMID      code    0x001010
    DB      0x30, 0x00, 0x03,ATYPE,AVERS,FVERS,FREV>>8,FREV
;            |     |     |     |     |     |     |_____|_____ firmware revision
;            |     |     |     |     |     |__________________ firmware version
;            |     |     |     |     |_____________________ application version
;            |     |     |     |______________________________ application type
;            |     |     |________________________________ hardware version '3'
;            |_____|______________________________________ hardware type 'UNIV'
;==============================================================================
;===  MOVED VECTORS  ==========================================================
;==============================================================================
;PROGRAM RESET VECTOR
FIRMRESET   code    0x1020
        goto    Main
;PROGRAM HIGH PRIORITY INTERRUPT VECTOR
FIRMHIGHINT code    0x1030
        call    HighInterrupt
        retfie
;PROGRAM LOW PRIORITY INTERRUPT VECTOR
FIRMLOWINT  code    0x1040
        call    LowInterrupt
        retfie

;==============================================================================
;===  FIRMWARE STARTS  ========================================================
;==============================================================================
FIRMSTART   code    0x001050
;------------------------------------------------------------------------------
;---  LOW PRIORITY INTERRUPT  -------------------------------------------------
;------------------------------------------------------------------------------
LowInterrupt
        movff   STATUS,STATUS_LOW           ;save STATUS register
        movff   WREG,WREG_LOW               ;save working register
        movff   BSR,BSR_LOW                 ;save BSR register
        movff   FSR0L,FSR0L_LOW             ;save other registers used in high int
        movff   FSR0H,FSR0H_LOW
        movff   FSR1L,FSR1L_LOW
        movff   FSR1H,FSR1H_LOW

    ;main firmware ready flag
        banksel FIRMREADY
        btfss   FIRMREADY,0
        bra     ExitLowInterrupt            ;main firmware is not ready yet
    ;CAN buffer
        banksel CANFULL
        btfsc   CANFULL,0                   ;check if CAN received anything
        call    CANInterrupt                ;proceed with CAN interrupt

ExitLowInterrupt
        movff   BSR_LOW,BSR                 ;restore BSR register
        movff   WREG_LOW,WREG               ;restore working register
        movff   STATUS_LOW,STATUS           ;restore STATUS register
        movff   FSR0L_LOW,FSR0L             ;restore other registers used in high int
        movff   FSR0H_LOW,FSR0H
        movff   FSR1L_LOW,FSR1L
        movff   FSR1H_LOW,FSR1H
    return
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

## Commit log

2013-09-25 hardware revision 1
    [pcb_univ_3-2-(3-4)-x-rev1.brd, pcb_univ_3-2-(3-4)-x-rev1.sch, univ_3-2-4-x-rev1-1coil.sch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]
2013-09-25 firmware revision 0
    [univ_3-2-4-0-rev0-memory.xlsx]
2015-03-16 firmware UNIV_3.2.4.1 rev0
    [univ_3-2-4-1-rev0-memory.xlsx]
2015-03-16 firmware UNIV 3.2.4.1 rev0
    [univ_3-2-4-1-rev0-memory.xlsx]
2015-04-01 hardware UNIV 3.2.4.x rev1
    [pcb_univ_3-2-(3-4)-x-rev1.brd, pcb_univ_3-2-(3-4)-x-rev1.sch, univ_3-2-4-x-rev1-1coil.sch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]
2015-04-01 hardware UNIV 3.2.4.x rev2
    [pcb_univ_3-2-(3-4)-x-rev2.brd, pcb_univ_3-2-(3-4)-x-rev2.sch, univ_3-2-4-x-rev2-1coil.sch]
2015-09-26 firmware UNIV 3.2.4.1 rev1
    [univ_3-2-4-1-rev1-memory.xlsx]
2018-03-04 firmware UNIV 3.2.4.2 revision 0
    [univ_3-2-4-2-rev0-memory.xlsx]
2022-10-07 firmware UNIV 3.2.4.3 revision 0
    [univ_3-2-4-3-rev0-memory.xlsx]

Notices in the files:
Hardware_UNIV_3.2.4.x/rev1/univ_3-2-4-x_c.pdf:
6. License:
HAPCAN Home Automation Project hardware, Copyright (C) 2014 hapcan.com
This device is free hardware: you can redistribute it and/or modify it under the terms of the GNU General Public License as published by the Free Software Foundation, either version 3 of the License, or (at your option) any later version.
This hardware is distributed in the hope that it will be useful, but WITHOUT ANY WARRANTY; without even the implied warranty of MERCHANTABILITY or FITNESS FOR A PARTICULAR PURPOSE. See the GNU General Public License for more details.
